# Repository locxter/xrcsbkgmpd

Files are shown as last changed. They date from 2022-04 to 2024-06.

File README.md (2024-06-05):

# xrcsbkgmpd

## Overview

> This project is **DEPRECATED**, therefore might not be on par with my current coding standards and will not receive any updates now or in the future.

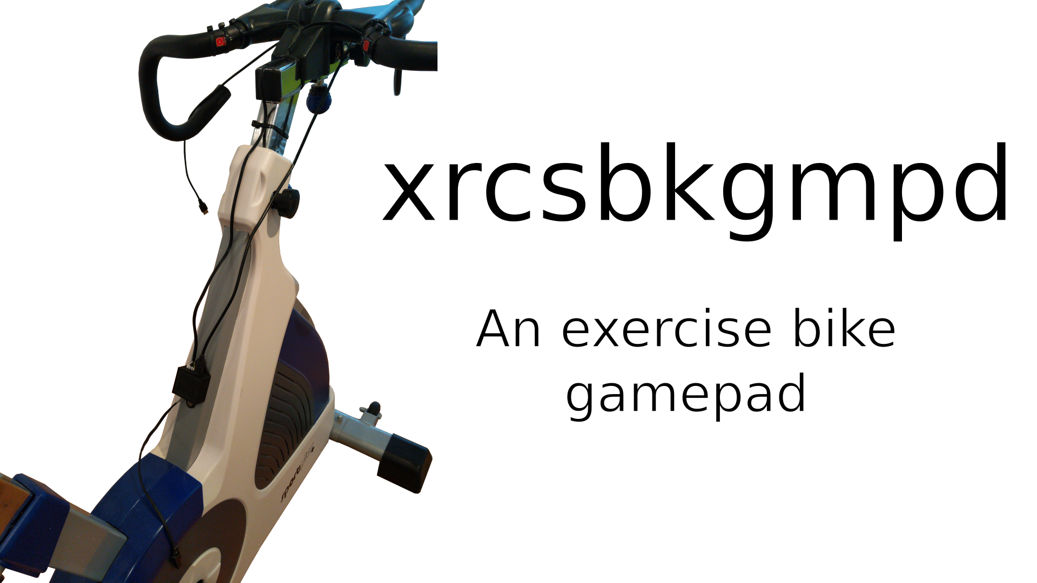
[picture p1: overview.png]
Overview image


This is an exercise bike gamepad I designed. In the default config it is set up to play [SuperTuxKart](https://supertuxkart.net/Main_Page) on a SportPlus SP-SRP-3000 exercise bike.

## Dependencies

I generally try to minimize dependencies, but I'm a one man crew and can therefore only support Debian-based Linux distributions as I'm running one myself. Anyway, you need to have the following packages installed for everything to work properly:

- FreeCAD for editing and exporting the CAD files. Install it with `sudo apt install freecad`.
- A2Plus for assemblying the different components in FreeCAD. Install it via the integrated addon manager.
- Arduino IDE as a way to compile the Arduino code. Install it with `sudo apt install arduino`.

## How to build it

This project is relatively straight forward as it mainly consists of an Arduino Pro Micro, one reed switch and 2 capacitive touch buttons all housed in 3D printed enclosures or simply glued onto the exercise bike in the case of the reed switch. For inspiration take a look at the overview image at the top as well as the mounting and assembly image down below.

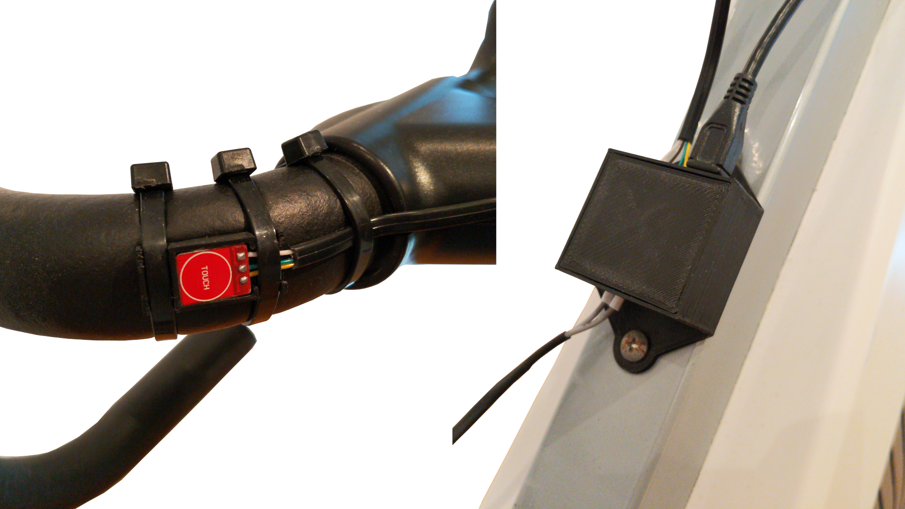
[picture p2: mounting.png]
Mounting image


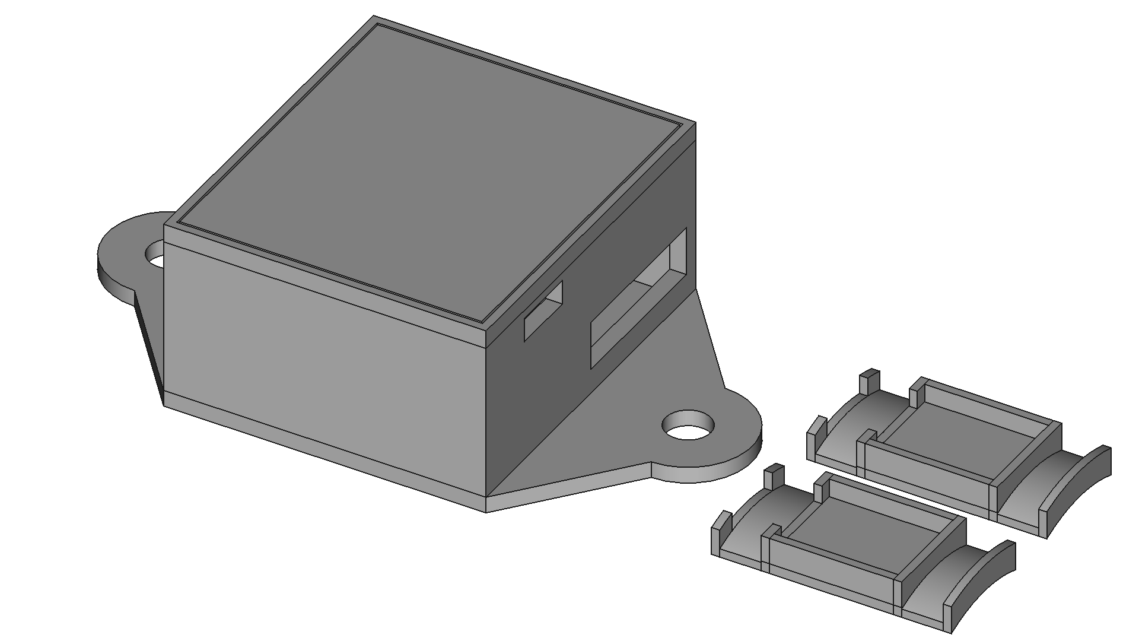
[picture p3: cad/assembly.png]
Assembly image


Below is a full bill of materials with German sources for all non-printable parts:

| Quantity: | Item: | Source: |
| --- | --- | --- |
| 1 | Instant glue | [Amazon](https://www.amazon.de/Pattex-Sekundenkleber-L%C3%B6sungsmittelfreier-Gel-Kleber-Transparent/dp/B00O23B8IE) |
| 1 | Cables | [Amazon](https://www.amazon.de/Donau-Elektronik-GMBH-Original-Kupfer/dp/B01BI1G88C) |
| 1 | Perfboard, pin header and screw terminal kit | [Amazon](https://www.amazon.de/70Stk-Doppelseitig-Lochrasterplatte-Kit-Lochrasterplatine/dp/B07BDKG68Q) |
| 1 | Cable ties | [Amazon](https://www.amazon.de/Kabelbinder-Rscolila-Hochleistungs-Kabelmanagement-300mmx5mm/dp/B08ZC7PBSD) |
| 1 | Arduino Pro Micro | [Amazon](https://www.amazon.de/Micro-ATmega32U4-Arduino-Leonardo-%C3%A4hnlich/dp/B01D0OI90U) |
| 1 | Reed switch | [Amazon](https://www.amazon.de/Gebildet-Magnetschalter-Magnetischer-Normalerweise-Geschlossener/dp/B085XQLQ3N) |
| 2 | Capacitive touch sensors | [Amazon](https://www.amazon.de/YOUMILE-Touch-Switch-Taste-Selbstsperrmodul-30-Pin-Header-Dupont-Leitung/dp/B07TTH5ZH9) |

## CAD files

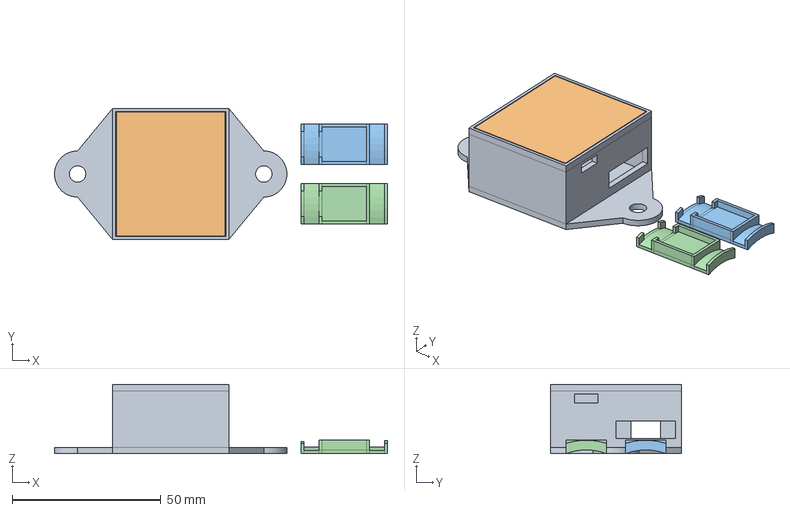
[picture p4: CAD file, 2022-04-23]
cad/assembly.FCStd
111.8 x 44.0 x 23.2 mm
base_001
top_001
trigger-mount_001
trigger-mount_002

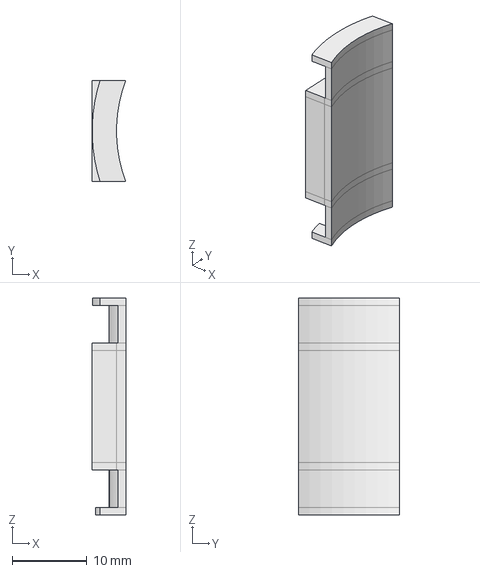
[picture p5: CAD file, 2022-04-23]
cad/trigger-mount.FCStd
4.49 x 13.5 x 29.0 mm

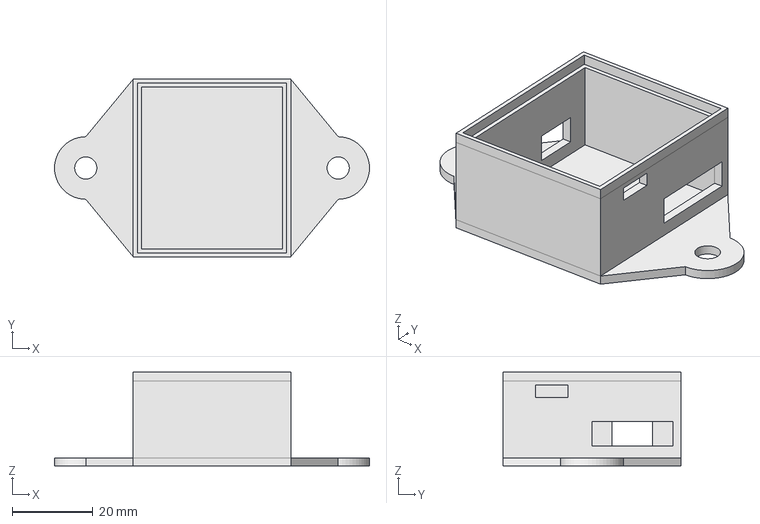
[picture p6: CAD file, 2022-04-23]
cad/base.FCStd
78.0 x 44.0 x 23.2 mm

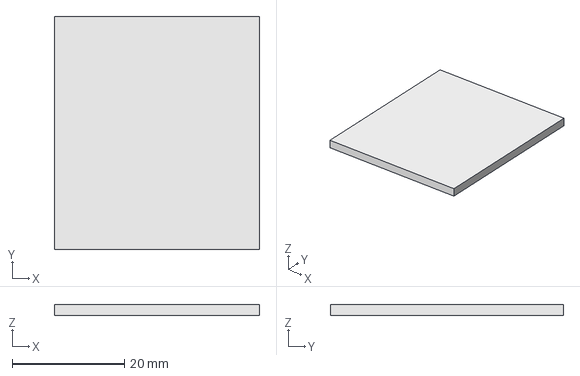
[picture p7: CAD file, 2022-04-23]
cad/top.FCStd
36.5 x 41.5 x 2.00 mm

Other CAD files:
cad/base.stl
cad/top.stl
cad/trigger-mount.stl

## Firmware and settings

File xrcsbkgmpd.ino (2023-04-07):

#include <Keyboard.h>

// Pins
const int LEFT_TRIGGER_PIN = 2;
const int RIGHT_TRIGGER_PIN = 3;
const int ROTATION_SENSOR_PIN = 4;

// Other variables
unsigned long currentMillis = 0;
unsigned long lastRotation = 0;
float rpm = 0;
float avgOldRpm = 0;
float oldRpms[30];
bool isUpPressed = false;
bool isLeftPressed = false;
bool isRightPressed = false;
bool isPaused = false;

// Setup function
void setup() {
    // Define pins as inputs
    pinMode(ROTATION_SENSOR_PIN, INPUT_PULLUP);
    pinMode(LEFT_TRIGGER_PIN, INPUT);
    pinMode(RIGHT_TRIGGER_PIN, INPUT);
    // Initialize keyboard functionality
    Keyboard.begin();
    // Wait for activation by user
    while (digitalRead(LEFT_TRIGGER_PIN) == LOW || digitalRead(RIGHT_TRIGGER_PIN) == LOW) {
        delay(100);
    }
    lastRotation = millis();
}

// Main function
void loop() {
    currentMillis = millis();
    // Calculate current RPM on every rotation when the user is pedalling and respond with a game input
    if (digitalRead(ROTATION_SENSOR_PIN) == HIGH && currentMillis - lastRotation >= 200 &&
        currentMillis - lastRotation <= 2000) {
        // Resume the game if it was previously paused
        if (isPaused) {
            Keyboard.write(KEY_ESC);
            delay(100);
            isPaused = false;
        }
        // Calculate RPM and average old RPM
        rpm = 60000.0 / (currentMillis - lastRotation);
        avgOldRpm = (oldRpms[0] + oldRpms[1] + oldRpms[2] + oldRpms[3] + oldRpms[4] + oldRpms[5] + oldRpms[6] +
                     oldRpms[7] + oldRpms[8] + oldRpms[9] + oldRpms[10] + oldRpms[11] + oldRpms[12] + oldRpms[13] +
                     oldRpms[14] + oldRpms[15] + oldRpms[16] + oldRpms[17] + oldRpms[18] + oldRpms[19] + oldRpms[20] +
                     oldRpms[21] + oldRpms[22] + oldRpms[23] + oldRpms[24] + oldRpms[25] + oldRpms[26] + oldRpms[27] +
                     oldRpms[28] + oldRpms[29]) /
                    30.0;
        // Accelerate + Nitro
        if (rpm > avgOldRpm + 5) {
            if (!isUpPressed) {
                Keyboard.press(KEY_UP_ARROW);
                isUpPressed = true;
            }
            Keyboard.write('N');
        }
        // Brake
        else if (rpm < avgOldRpm - 5 && isUpPressed) {
            Keyboard.release(KEY_UP_ARROW);
            isUpPressed = false;
        }
        // Accelerate
        else if (rpm <= avgOldRpm + 5 && rpm >= avgOldRpm - 5 && !isUpPressed) {
            Keyboard.press(KEY_UP_ARROW);
            isUpPressed = true;
        }
        // Update old RPMs
        for (int i = 29; i > 0; i--) {
            oldRpms[i] = oldRpms[i - 1];
        }
        oldRpms[0] = rpm;
        lastRotation = currentMillis;
    }
    // Pause game when user stops pedalling
    if (currentMillis - lastRotation > 2000) {
        if (!isPaused) {
            Keyboard.releaseAll();
            Keyboard.write(KEY_ESC);
            rpm = 0;
            avgOldRpm = 0;
            for (int i = 0; i < 30; i++) {
                oldRpms[i] = 0;
            }
            isUpPressed = false;
            isLeftPressed = false;
            isRightPressed = false;
            isPaused = true;
        }
        lastRotation = currentMillis;
    }
    if (!isPaused) {
        // Fire
        if (digitalRead(LEFT_TRIGGER_PIN) == HIGH && digitalRead(RIGHT_TRIGGER_PIN) == HIGH) {
            Keyboard.write(' ');
        } else {
            // Steer left
            if (digitalRead(LEFT_TRIGGER_PIN) == HIGH && !isLeftPressed) {
                Keyboard.press(KEY_LEFT_ARROW);
                isLeftPressed = true;
            } else if (digitalRead(LEFT_TRIGGER_PIN) == LOW && isLeftPressed) {
                Keyboard.release(KEY_LEFT_ARROW);
                isLeftPressed = false;
            }
            // Steer right
            if (digitalRead(RIGHT_TRIGGER_PIN) == HIGH && !isRightPressed) {
                Keyboard.press(KEY_RIGHT_ARROW);
                isRightPressed = true;
            } else if (digitalRead(RIGHT_TRIGGER_PIN) == LOW && isRightPressed) {
                Keyboard.release(KEY_RIGHT_ARROW);
                isRightPressed = false;
            }
        }
    }
}

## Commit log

2022-04-23 Uploaded already existing files.
    [assembly.FCStd, base.FCStd, base.stl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]
2022-09-11 Switched back to Ubuntu due to hardware compatibility.
2022-10-16 Switched back to good old Linux Mint.
2022-11-06 Fixed some edge cases.
    [xrcsbkgmpd.ino]
